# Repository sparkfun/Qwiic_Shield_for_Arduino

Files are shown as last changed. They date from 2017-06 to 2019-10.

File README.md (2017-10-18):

SparkFun Qwiic Shield for Arduino
========================================

SparkFun Qwiic Shield for Arduino

[*SparkFun Qwiic Shield (DEV-14352)*](https://www.sparkfun.com/products/14352)

An Arduino shield to connect the I<sup>2</sup>C bus to 4 Qwiic connect ports.

Repository Contents
-------------------

* **/Hardware** - Eagle design files (.brd, .sch)

Documentation
--------------

* **[Hookup Guide](https://learn.sparkfun.com/tutorials/qwiic-shield-for-arduino--photon-hookup-guide)** - Basic hookup guide for the Arduino Qwiic Shield
* **[SparkFun Fritzing repo](https://github.com/sparkfun/Fritzing_Parts)** - Fritzing diagrams for SparkFun products.
* **[SparkFun 3D Model repo](https://github.com/sparkfun/3D_Models)** - 3D models of SparkFun products. 
* **[SparkFun Graphical Datasheets](https://github.com/sparkfun/Graphical_Datasheets)** -Graphical Datasheets for various SparkFun products.

Product Versions
----------------
* [DEV-14352](https://www.sparkfun.com/products/14352)- An Arduino shield to connect the I<sup>2</sup>C bus to 4 Qwiic connect ports.

Version History
---------------
* [V1.0.0](https://github.com/sparkfun/Qwiic_Shield_for_Arduino/releases/tag/V_1.0.0) - Initial Release

License Information
-------------------

This product is _**open source**_! 

Please review the LICENSE.md file for license information. 

If you have any questions or concerns on licensing, please contact techsupport@sparkfun.com.

Distributed as-is; no warranty is given.

- Your friends at SparkFun.

_<COLLABORATION CREDIT>_

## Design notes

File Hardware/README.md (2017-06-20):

SparkFun <PRODUCT NAME> Design Files
=====================================

The .sch and .brd files hare are Eagle CAD schematic and PCB design files from SparkFun Electronics.
A freeware version of Eagle can be found [here](http://www.cadsoftusa.com/download-eagle/freeware/).

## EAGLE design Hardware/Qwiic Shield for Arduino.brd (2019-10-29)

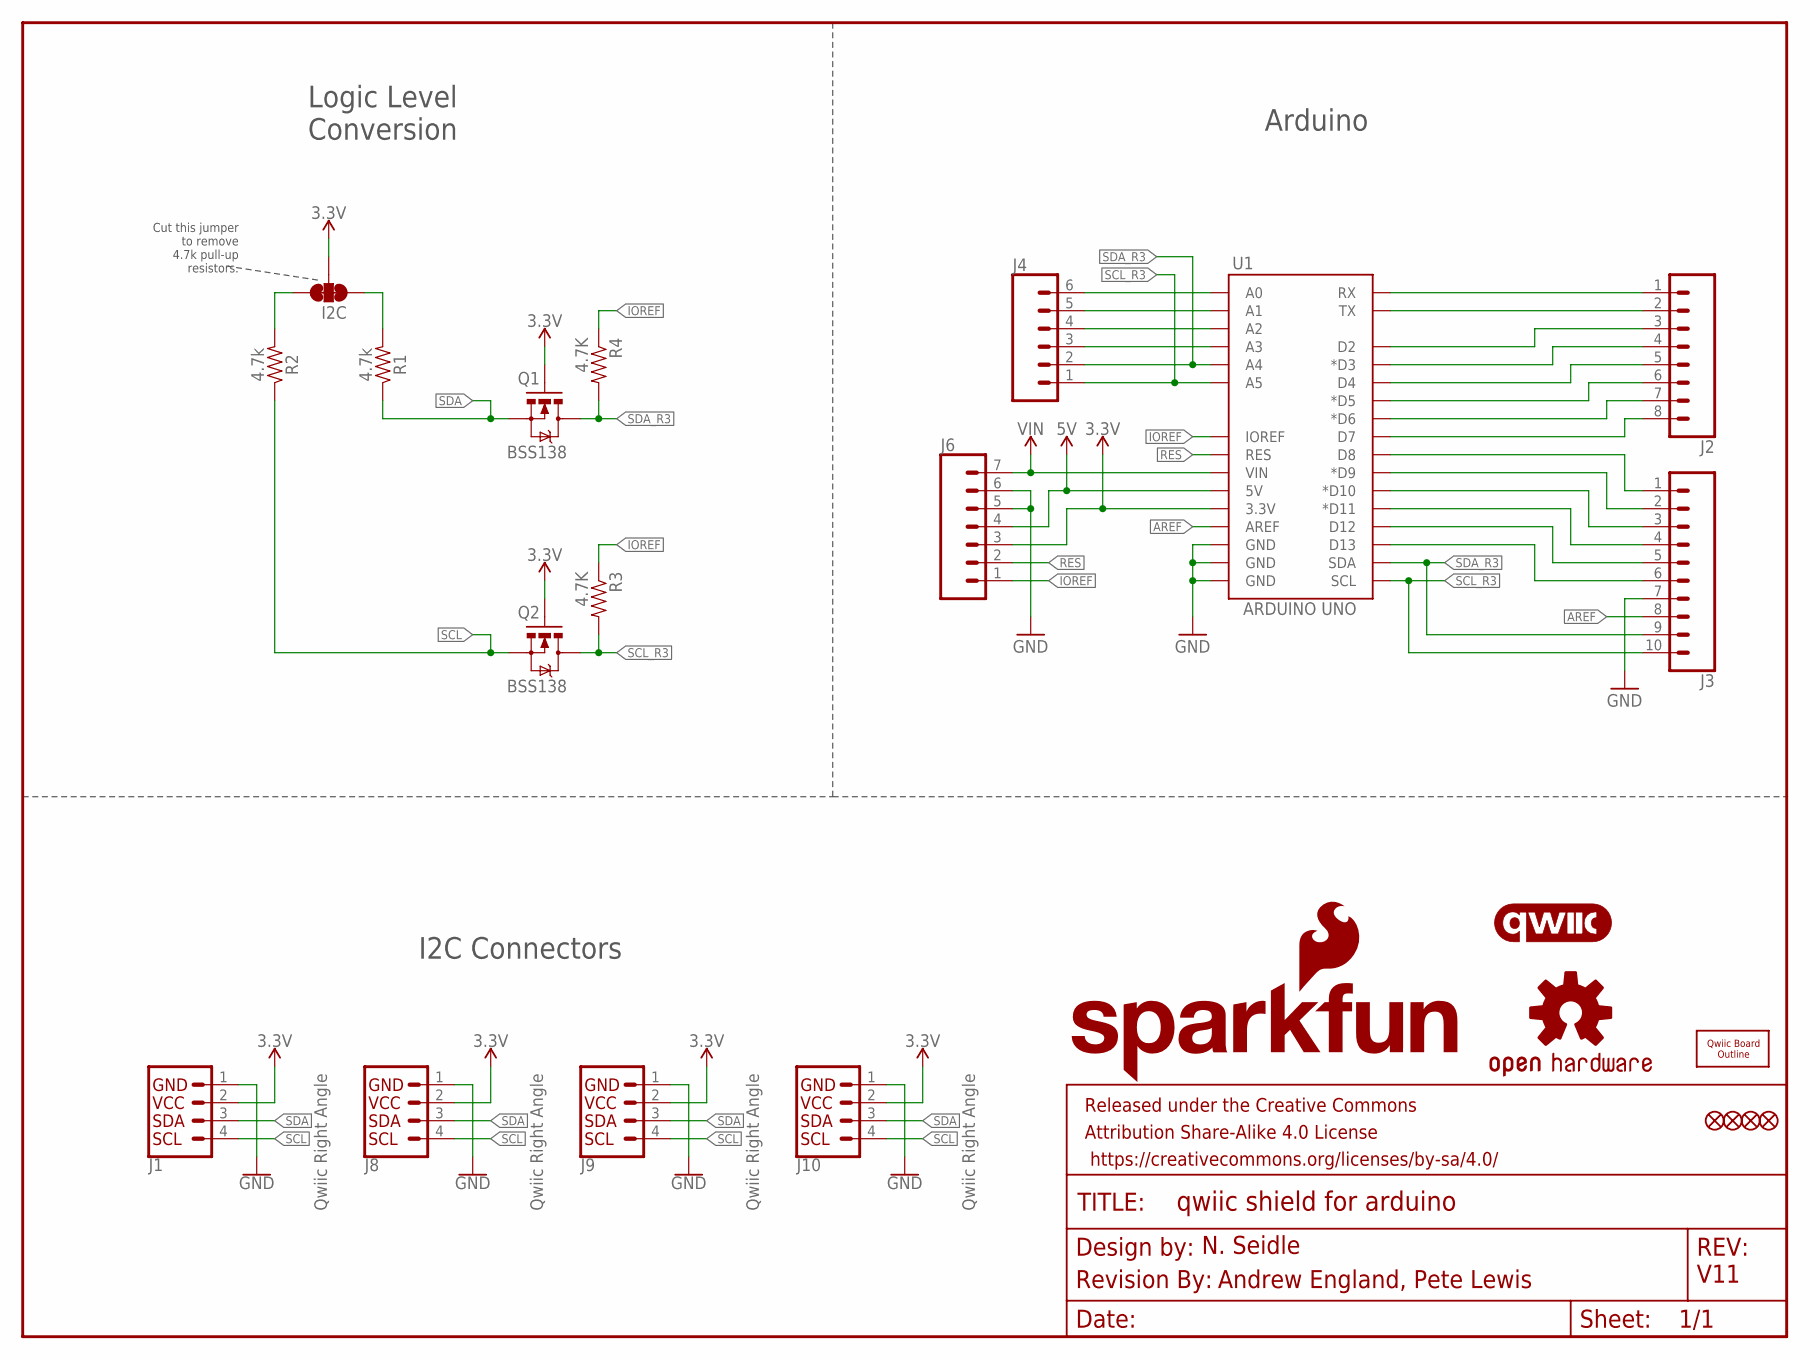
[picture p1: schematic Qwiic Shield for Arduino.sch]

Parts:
FD1, FD2, FD3, FD4: FIDUCIAL1X2; FIDUCIAL-1X2
FRAME1: FRAME-LETTER; CREATIVE_COMMONS
I2C: JUMPER-SMT_3_2-NC_TRACE_SILK; SMT-JUMPER_3_2-NC_TRACE_SILK
J1, J8, J9, J10: Qwiic Right Angle; 1X04_1MM_RA
J2: CONN_08NO_SILK_FEMALE_PTH; 1X08_NO_SILK
J3: CONN_10NO_SILK_PTH_FEMALE; 1X10_NO_SILK
J4: CONN_06NO_SILK_FEMALE_PTH; 1X06_NO_SILK
J6: CONN_07NO_SILK; 1X07_NO_SILK
LOGO1: OSHW-LOGOMINI; OSHW-LOGO-MINI
LOGO2: REVISION
LOGO3: QWIIC_LOGO_6MM; QWIIC_6MM
Q1, Q2: BSS138; SOT23-3
R1, R2: 4.7k; 0603
R3, R4: 4.7K; 0603-RES
U1: ARDUINO UNO; UNO_R3_SHIELD_NOLABELS
U$2: SFE_LOGO_NAME_FLAME.1_INCH; SFE_LOGO_NAME_FLAME_.1
U$3: QWIIC_BOARD_OUTLINEH; QWIIC_BOARD_MOUNT_HOLES

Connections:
3.3V: I2C.2, J1.2, J6.3, J8.2, J9.2, J10.2, Q1.1 (G), Q2.1 (G), U1.3.3V
5V: J6.4, U1.5V
A0: J4.6, U1.A0
A1: J4.5, U1.A1
A2: J4.4, U1.A2
A3: J4.3, U1.A3
AREF: J3.8, U1.AREF
D2: J2.3, U1.D2
D3: J2.4, U1.D3 (*D3)
D4: J2.5, U1.D4
D5: J2.6, U1.D5 (*D5)
D6: J2.7, U1.D6 (*D6)
D7: J2.8, U1.D7
D8: J3.1, U1.D8
D9: J3.2, U1.D9 (*D9)
D10: J3.3, U1.D10 (*D10)
D11: J3.4, U1.D11 (*D11)
D12: J3.5, U1.D12
D13: J3.6, U1.D13
GND: J1.1, J3.7, J6.5, J6.6, J8.1, J9.1, J10.1, U1.GND@0 (GND), U1.GND@1 (GND), U1.GND@2 (GND)
IOREF: J6.1, R3.1, R4.1, U1.IOREF
unnamed: I2C.3, R1.2
unnamed: I2C.1, R2.2
RES: J6.2, U1.RES
RX: J2.1, U1.RX
SCL: J1.4, J8.4, J9.4, J10.4, Q2.2 (S), R2.1
SCL_R3: J3.10, J4.1, Q2.3 (D), R3.2, U1.A5, U1.SCL
SDA: J1.3, J8.3, J9.3, J10.3, Q1.2 (S), R1.1
SDA_R3: J3.9, J4.2, Q1.3 (D), R4.2, U1.A4, U1.SDA
TX: J2.2, U1.TX
VIN: J6.7, U1.VIN

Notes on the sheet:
N. Seidle
Logic Level Conversion
Arduino
V11
I2C Connectors
Andrew England, Pete Lewis
Cut this jumper to remove 4.7k pull-up resistors.

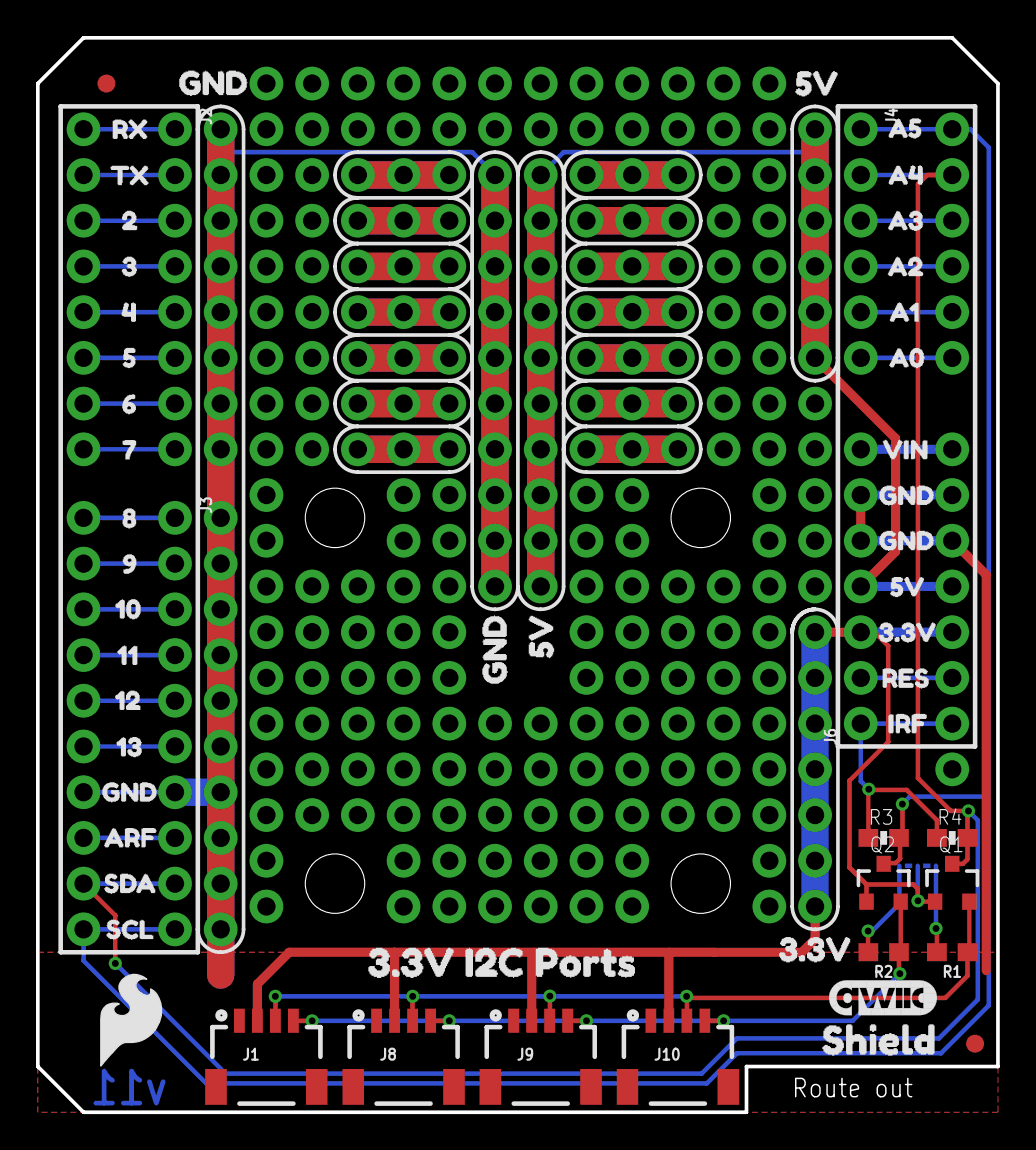
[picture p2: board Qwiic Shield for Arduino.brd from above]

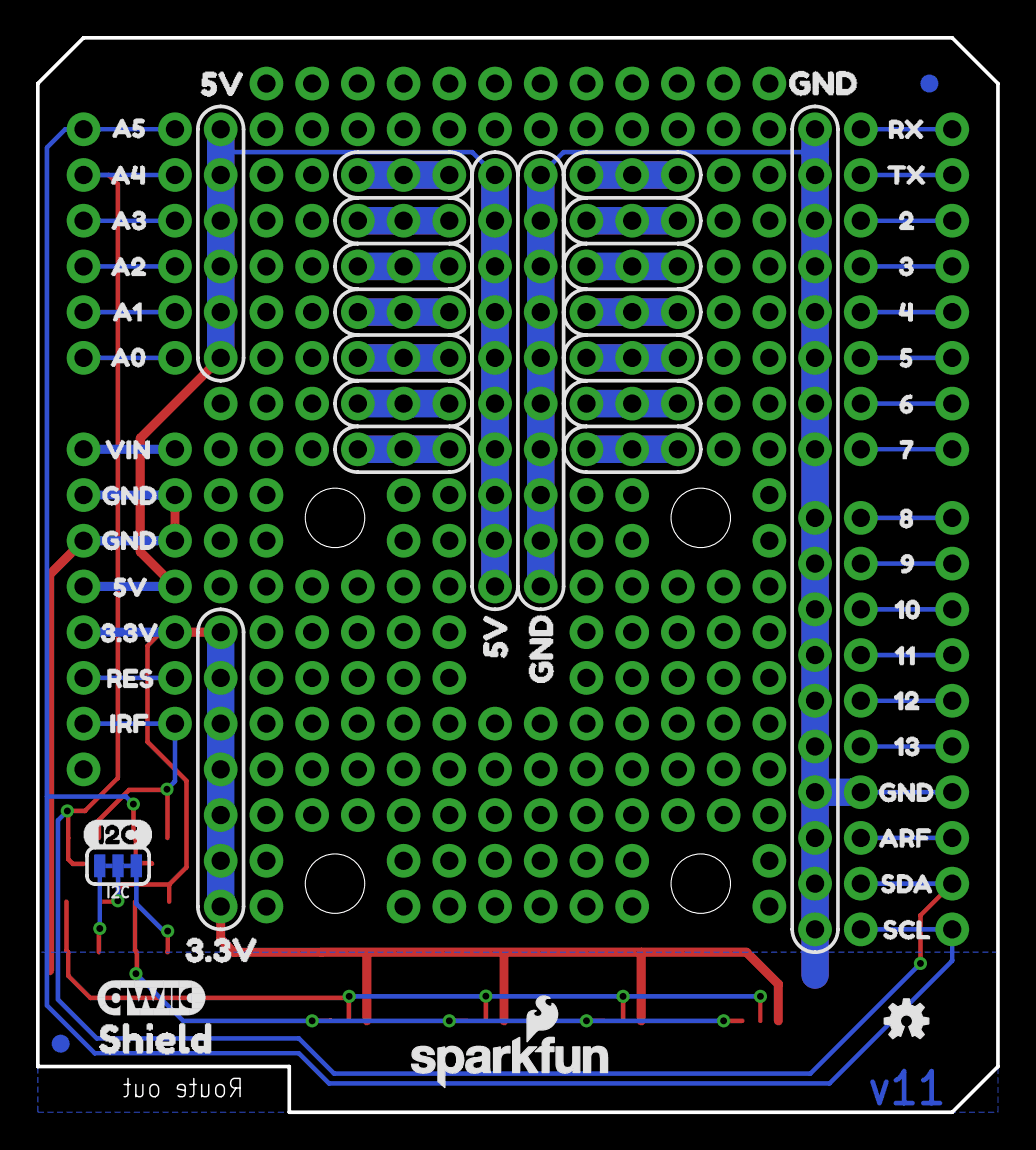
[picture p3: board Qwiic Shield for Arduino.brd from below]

Board: 2 copper layers, 53.3 x 59.7 mm, 104 parts (44 on the bottom side), 31 nets.

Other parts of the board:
LOGO4: QWIIC_LOGO_6MM; QWIIC_6MM
U$1: SFE_LOGO_FLAME_.2
U$4, U$5: SHIELD0
U$6: 3#3V_I2C_PORTS1
U$7, U$8: RX5
U$9, U$10: TX6
U$11, U$12: 27
U$13, U$14: 38
U$15, U$16: 49
U$17, U$18: 510
U$19, U$20: 611
U$21, U$23: 712
U$22: I2C0
U$24, U$25: 813
U$26, U$27: 914
U$28, U$29: 1015
U$30, U$31: 1116
U$32, U$33: 1217
U$34, U$35: 1318
U$36, U$37, U$68, U$69, U$70, U$71: GND30
U$38, U$39: ARF20
U$40, U$41: SDA21
U$42, U$43: SCL22
U$44, U$45, U$46, U$47: GND2
U$48, U$49: 3#3V4
U$50, U$51, U$52, U$53: 5V3
U$54, U$55: A523
U$56, U$57: A424
U$58, U$59: A325
U$60, U$61: A226
U$62, U$63: A127
U$64, U$65: A028
U$66, U$67: VIN29
U$72, U$73: 5V31
U$74, U$75: 3#3V32
U$76, U$77: RES33
U$78, U$79: IRF34

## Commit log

2017-06-16 added eagle files
    [Qwiic Shield for Arduino.brd, Qwiic Shield for Arduino.sch]
2017-06-20 Updated file structure to match SFE repo
    [Qwiic Shield for Arduino.brd, Qwiic Shield for Arduino.sch]
2017-06-20 Changed over to Sparkfun library from SparkX
    [Qwiic Shield for Arduino.brd, Qwiic Shield for Arduino.sch]
2017-07-10 Partially completed checklist, changes still need to be made
    [Board_Design_Checklist.xls, Board_Design_Checklist_Qwiic Shield for Arduino_.xls, Qwiic Shield for Arduino.brd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]
2017-07-17 Completed checklist + pre-design review changes
    [Board_Design_Checklist_Qwiic Shield for Arduino_.xls, Qwiic Shield for Arduino.brd, Qwiic Shield for Arduino.sch]
2017-07-17 Added mask and silk outline to rails. Added 3.3V Rail
    [Qwiic Shield for Arduino.brd]
2017-07-18 added units
    [Qwiic Shield for Arduino.brd]
2017-07-18 Added flame
    [Qwiic Shield for Arduino.brd, Qwiic Shield for Arduino.sch]
2017-07-25 changed version number
    [Qwiic Shield for Arduino.brd]
2017-08-07 fixed aesthetic issues with power rails
    [Qwiic Shield for Arduino.brd]
2017-08-14 Added notch for barrel jack
    [Qwiic Shield for Arduino.brd]
2017-08-14 Post Design review changes
    [Qwiic Shield for Arduino.brd]
2017-08-18 Fixed route out in lower right corner
    [Qwiic Shield for Arduino.brd]
2017-08-23 Moved engineering checklist
    [Board_Design_Checklist.xls, Board_Design_Checklist_Qwiic Shield for Arduino_.xls]
2017-10-18 Initial Release
    [Board_Design_Checklist_Qwiic Shield for Arduino_.xls]
2019-10-29 Connected R3 SDA/SCL pins and IOREF
    -SDA and SCL are now connected to both A4 /A5 pins and SDA/SCL pins.
    -Changed "high" logic side of converters to IOREF, to allow the Arduino to supply it's own IOREF. This will allow the shield to work with 3.3V logic Arduinos.
    -named PTH headers in the row of 3.3V to avoid overlap DRC errors.
    bumped version to v11 insch and brd
    - Added I2C pullup jumper to bottom side with label
    - rerouted SDA/SCL to allow for better GND return in pour
    - bumped up 3.3V traces to 0.020 inch for qwiic connectors
    - all labels to buzzrds and included qwiic logo
    [Qwiic Shield for Arduino.brd, Qwiic Shield for Arduino.sch]
2019-10-29 Moved resistors to original location to maintain stencil spacing
    [Qwiic Shield for Arduino.brd]
2019-10-29 Moved qwiic board to SFE library
    [Qwiic Shield for Arduino.brd, Qwiic Shield for Arduino.sch]
2019-10-29 net flags
    [Qwiic Shield for Arduino.sch]
2019-10-29 moved via away from qwiic silk logo
    [Qwiic Shield for Arduino.brd]

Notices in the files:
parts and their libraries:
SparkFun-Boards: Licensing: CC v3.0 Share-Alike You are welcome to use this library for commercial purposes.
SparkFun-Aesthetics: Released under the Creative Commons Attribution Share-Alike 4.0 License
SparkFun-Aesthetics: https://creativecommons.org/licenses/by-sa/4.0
